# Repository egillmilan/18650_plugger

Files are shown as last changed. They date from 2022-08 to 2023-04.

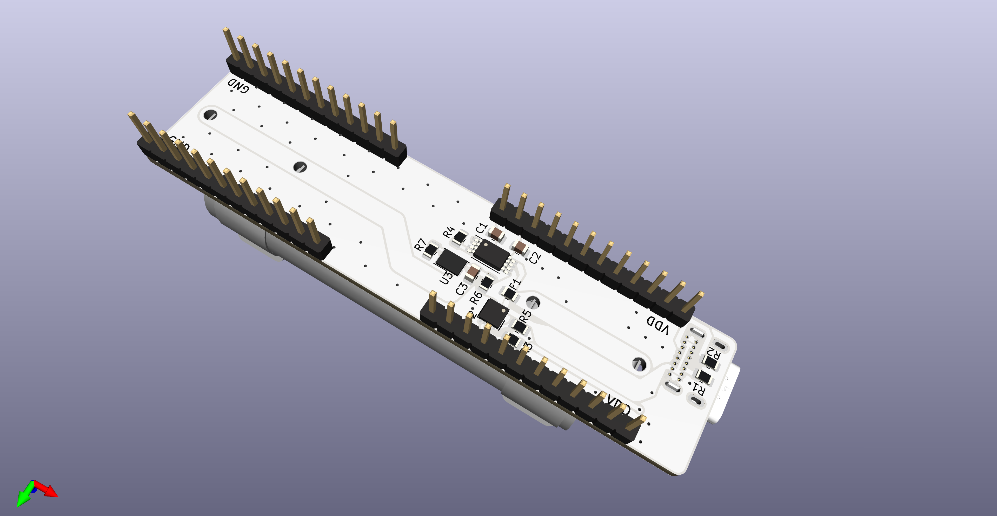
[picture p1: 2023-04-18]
18650_Plugger_v1/images/18650_Plugger_v1_2.png

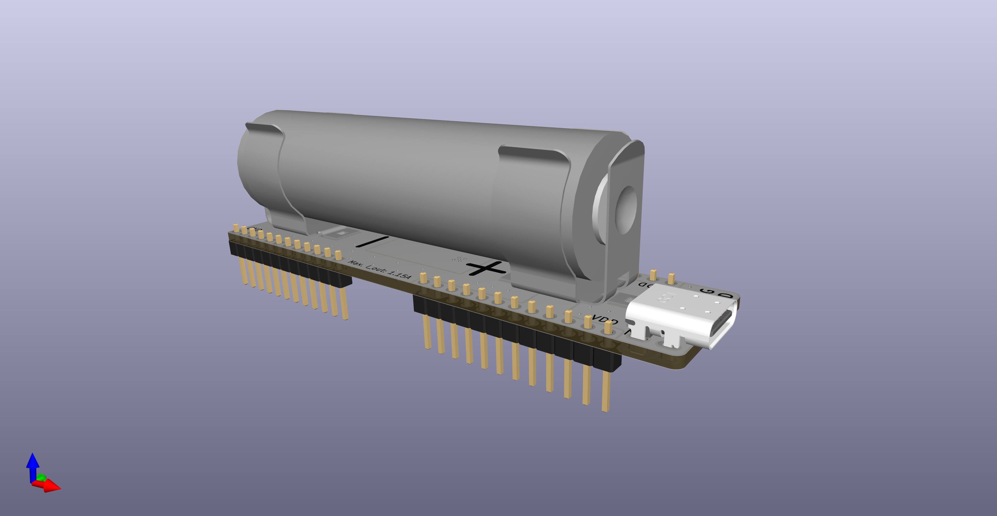
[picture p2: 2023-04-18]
18650_Plugger_v1/images/18650_Plugger_v1_1.png

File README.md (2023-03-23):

# 18650 plugger
A carrier board for a single 18650 Li-ion cell with all the appropriate protection and charging circuitry. The idea is to have a simple plug-and-play solution for batterizing any electronics project without having to deal with all the hassle of Li-ion batteries. The board also includes an OR-contoller allowing for the project to run on the power from the charger while the battery is getting charged. Note that this requires a charger that is able to provide enough current to charge the battery and power the project simultaneously.
18650_Plugger_v1_1
18650_Plugger_v1_2
18650_Plugger_v1_3

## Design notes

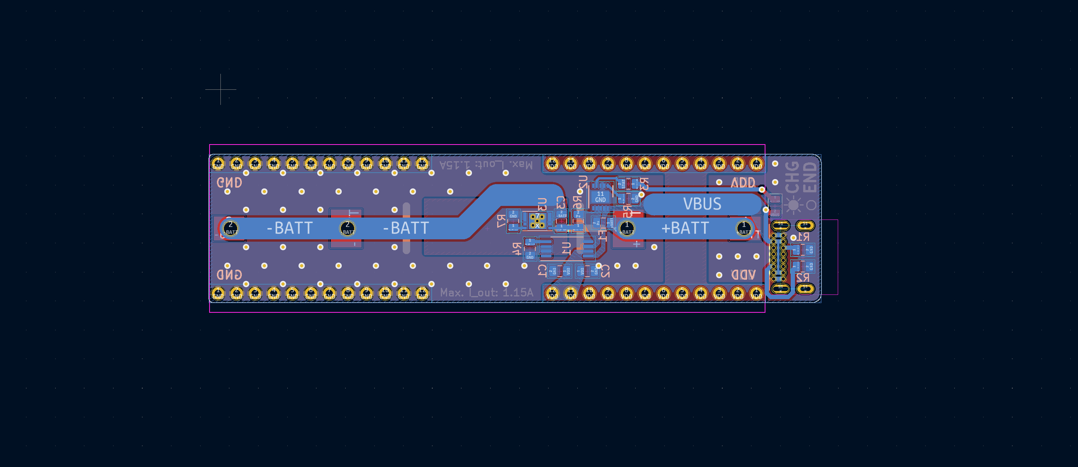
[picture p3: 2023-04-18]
18650_Plugger_v1/images/18650_Plugger_v1_3.png

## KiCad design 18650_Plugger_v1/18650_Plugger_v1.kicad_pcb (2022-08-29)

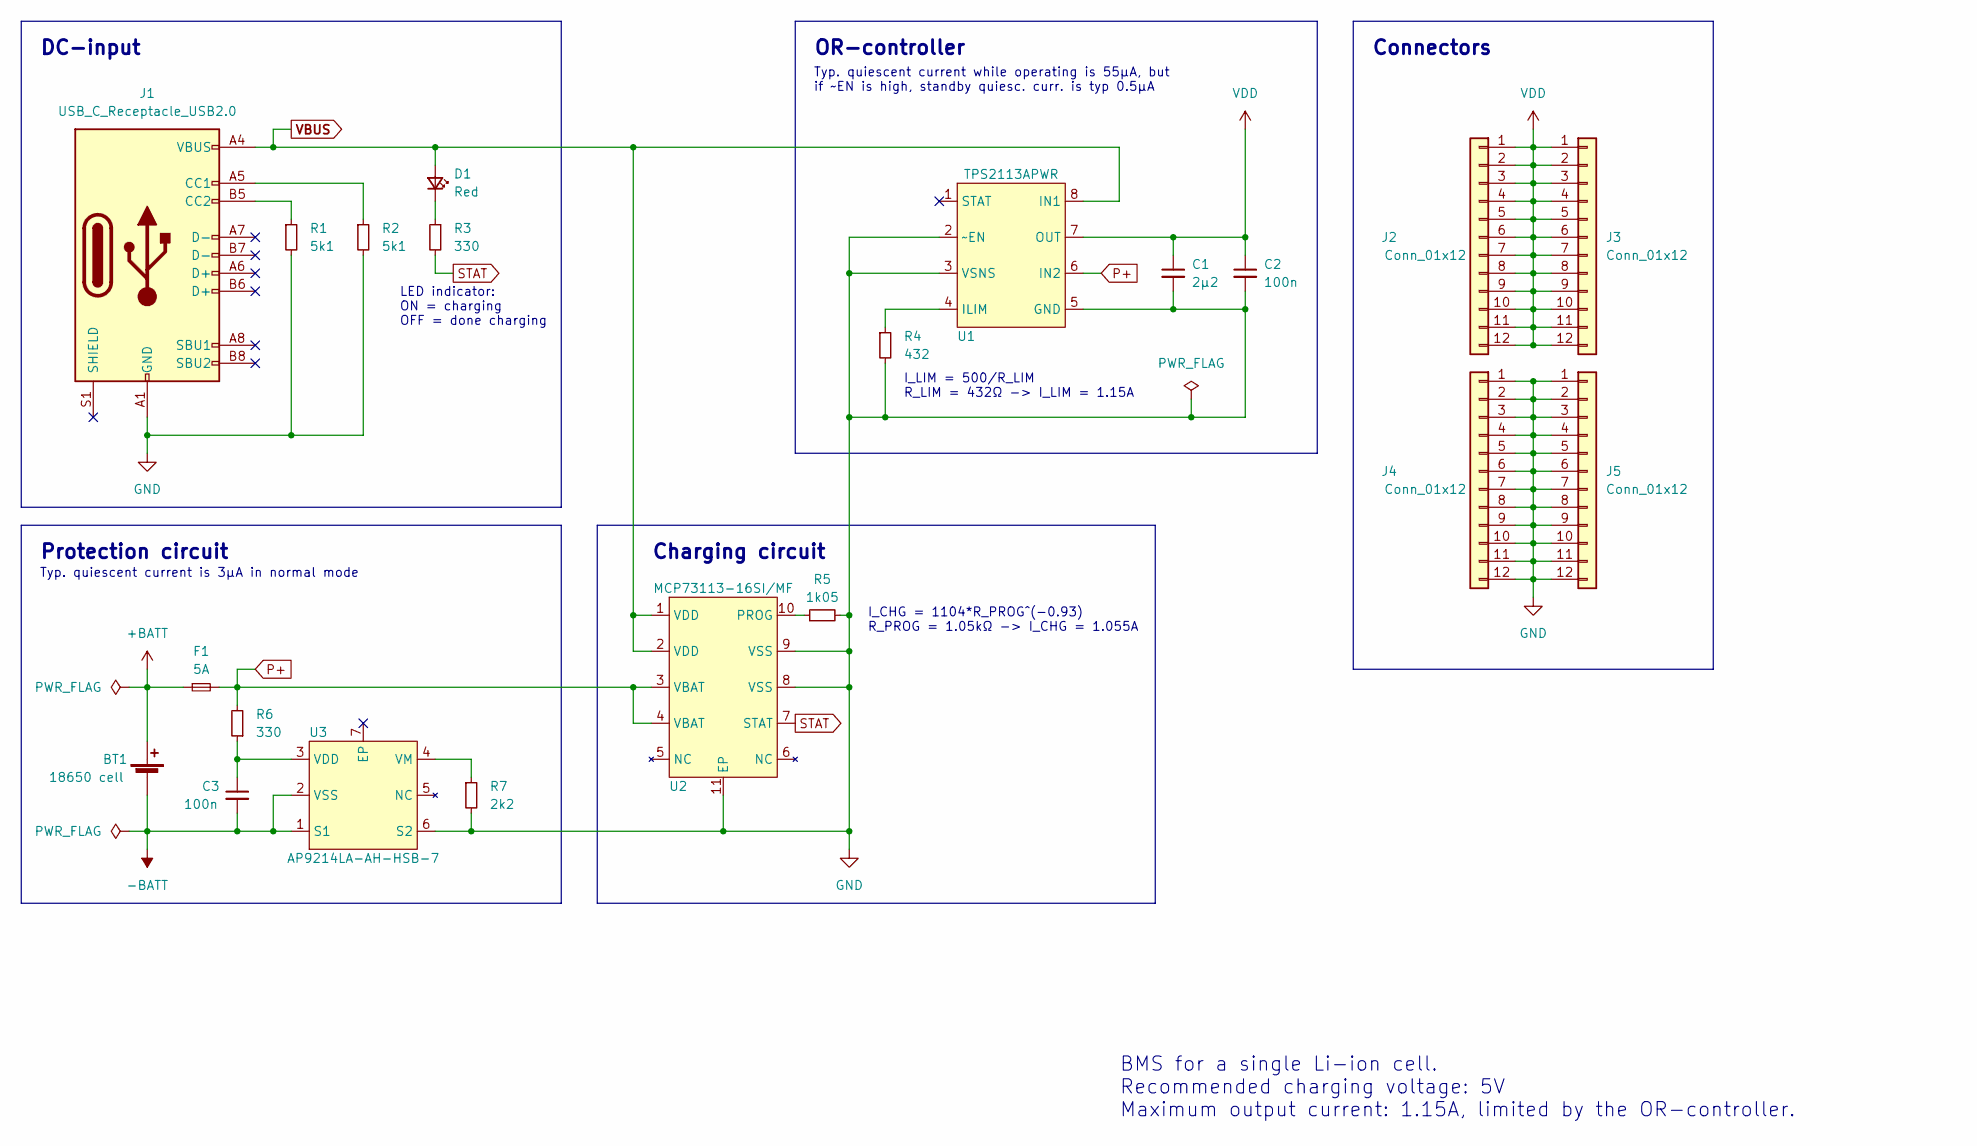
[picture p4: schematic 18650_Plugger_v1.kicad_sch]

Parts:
BT1: 18650 cell; Keystone_254_holder
C1: 2µ2; C_0805_2012Metric
C2, C3: 100n; C_0805_2012Metric
D1: Red; LED_0805_2012Metric
F1: 5A; Fuse_0805_2012Metric
J1: USB_C_Receptacle_USB2.0; GCT_USB4085-GF-A
J2, J3, J4, J5: Conn_01x12; PinHeader_1x12_P2.54mm_Vertical
R1, R2: 5k1; R_0805_2012Metric
R3, R6: 330; R_0805_2012Metric
R4: 432; R_0805_2012Metric
R5: 1k05; R_0805_2012Metric
R7: 2k2; R_0805_2012Metric
U1: TPS2113APWR; TSSOP-8_4.4x3mm_P0.65mm
U2: MCP73113-16SI/MF; DFN-10-1EP_3x3mm_P0.5mm_EP1.55x2.48mm
U3: AP9214LA-AH-HSB-7; U-DFN2535-6 (Type B)

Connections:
+BATT: BT1.1 (+), F1.1
-BATT: BT1.2 (-), C3.2, U3.1 (S1), U3.2 (VSS)
GND: C1.2, C2.2, J1.A1 (GND), J1.A12 (GND), J1.B1 (GND), J1.B12 (GND), J4.1, J4.2, J4.3, J4.4, J4.5, J4.6, J4.7, J4.8, J4.9, J4.10, J4.11, J4.12, J5.1, J5.2, J5.3, J5.4, J5.5, J5.6, J5.7, J5.8, J5.9, J5.10, J5.11, J5.12, R1.2, R2.2, R4.2, R5.2, R7.2, U1.2 (~EN), U1.3 (VSNS), U1.5 (GND), U2.8 (VSS), U2.9 (VSS), U2.11 (EP), U3.6 (S2)
unnamed: C3.1, R6.1, U3.3 (VDD)
unnamed: D1.1 (K), R3.1
unnamed: J1.A5 (CC1), R2.1
unnamed: J1.B5 (CC2), R1.1
unnamed: R4.1, U1.4 (ILIM)
unnamed: R5.1, U2.10 (PROG)
unnamed: R7.1, U3.4 (VM)
P+: F1.2, R6.2, U1.6 (IN2), U2.3 (VBAT), U2.4 (VBAT)
STAT: R3.2, U2.7 (STAT)
VBUS: D1.2 (A), J1.A4 (VBUS), J1.A9 (VBUS), J1.B4 (VBUS), J1.B9 (VBUS), U1.8 (IN1), U2.1 (VDD), U2.2 (VDD)
VDD: C1.1, C2.1, J2.1, J2.2, J2.3, J2.4, J2.5, J2.6, J2.7, J2.8, J2.9, J2.10, J2.11, J2.12, J3.1, J3.2, J3.3, J3.4, J3.5, J3.6, J3.7, J3.8, J3.9, J3.10, J3.11, J3.12, U1.7 (OUT)

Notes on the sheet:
LED indicator: ON = charging OFF = done charging
Connectors
OR-controller
I_CHG = 1104*R_PROG^(-0.93) R_PROG = 1.05kΩ -> I_CHG = 1.055A
Typ. quiescent current is 3µA in normal mode
Charging circuit
BMS for a single Li-ion cell. Recommended charging voltage: 5V Maximum output current: 1.15A, limited by the OR-controller.
DC-input
Typ. quiescent current while operating is 55µA, but if ~EN is high, standby quiesc. curr. is typ 0.5µA
I_LIM = 500/R_LIM R_LIM = 432Ω -> I_LIM = 1.15A
Protection circuit

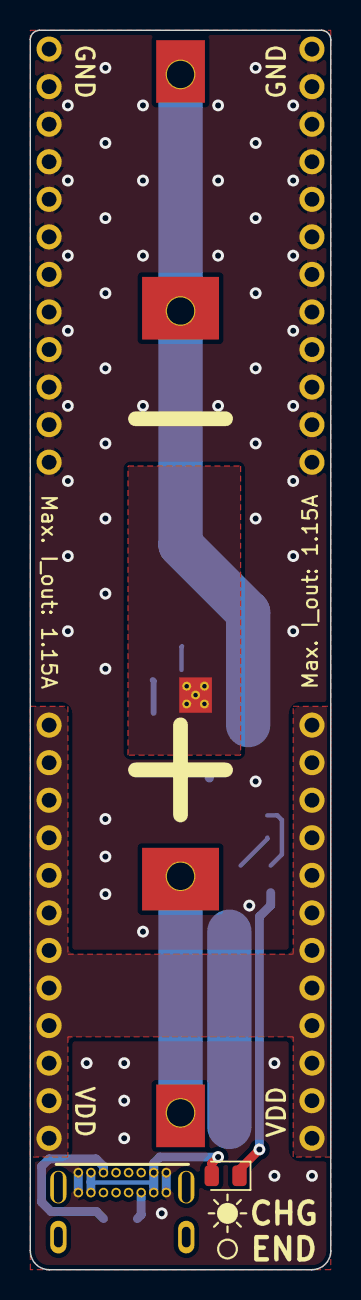
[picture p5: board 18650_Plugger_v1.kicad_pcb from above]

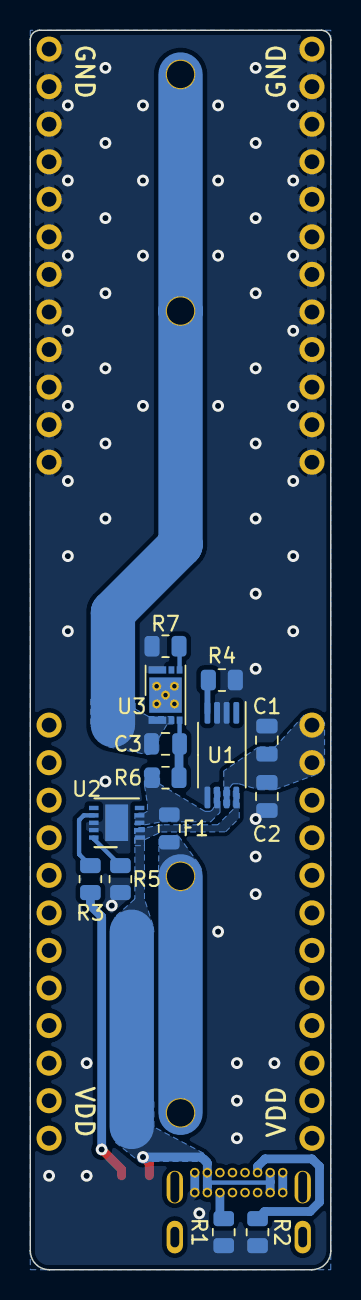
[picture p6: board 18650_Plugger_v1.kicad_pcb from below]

Board: 2 copper layers, 20.3 x 83.8 mm, 21 parts (18 on the bottom side), 14 nets.
